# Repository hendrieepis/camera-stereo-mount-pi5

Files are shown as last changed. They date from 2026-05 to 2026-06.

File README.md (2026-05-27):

# Camera Stereo Mount Pi5 — 90°

Dudukan kamera CSI stereo untuk Raspberry Pi 5, konfigurasi siku 90°.
Repo ini berisi empat versi desain (V3, V4, V5, V6) dalam format OpenSCAD `.scad`.

---

## Kamera yang Didukung

Waveshare IMX219-83 Stereo Camera

Desain mount ini dibuat dan diuji untuk kamera:

**Waveshare Binocular Camera Module — IMX219-83 Stereo Camera**
- Sensor: Dual IMX219, 8 Megapixel per lensa
- FOV: 83°
- Antarmuka: CSI (kompatibel Raspberry Pi 5 dan Jetson Nano)
- Fitur: Stereo vision, depth vision
- Jarak antar lubang baut: 20.45mm (X) × 13.87mm (Y)
- Baut mounting: M2

Beli di: [Waveshare IMX219-83 Stereo Camera](https://www.waveshare.com/product/raspberry-pi/boards-kits/raspberry-pi-5/imx219-83-stereo-camera.htm)

---

## Perbedaan V3, V4, V5, V6

Keempat versi punya fungsi sama — menahan pelat kamera tegak lurus terhadap base
yang dibaut ke casing Raspberry Pi 5. Yang berbeda adalah **cara part disambung
dan apakah sudut kamera bisa disetel**.

| Aspek | V3 | V4 | V5 | V6 |
|---|---|---|---|---|
| Penyambung | Ball head (beli) | Batang ulir terpisah | Tidak ada — menyatu | Engsel knuckle BOSL2 |
| Jumlah part cetak | 2 | 3 | 1 | 2 |
| Ulir | 1/4"-20 (ke ball head) | 1/4"-20 (di rod) | Tidak ada | Tidak ada |
| Bisa dibongkar | Ya | Ya | Tidak | Ya |
| Setel sudut tilt | Ya (via ball head) | Tidak | Tidak | Ya, ±15° atas-bawah |
| Komponen beli | Ball head 1/4" | Threaded rod / baut M4 | — | Baut M4×25mm + mur M4 |

### V3 — dengan ball head
Part atas dan part bawah tidak tersambung langsung. Di antara keduanya
dipasang **ball head** (komponen tripod yang dibeli jadi). Part bawah punya
ulir male di puncak stick yang masuk ke lubang female ball head; part atas
punya lubang female yang menerima ulir male di atas ball head. Ball head
memberi kebebasan mengatur sudut kamera ke segala arah.

### V4 — batang ulir terpisah
Ball head dihilangkan. Sebagai gantinya dipakai **connector rod**: satu
batang dengan ulir male 1/4"-20 di kedua ujung dan batang polos di tengah.
Part atas dan part bawah dua-duanya punya lubang ulir female; connector rod
disekrup ke keduanya. Masih bisa dibongkar, tetapi sudut sudah tetap (90°).

Connector rod bisa dicetak, namun **disarankan memakai threaded rod 1/4"-20
dari logam** (potong sepanjang ±26 mm) karena ulir hasil cetak FDM rapuh
terhadap puntiran.

### V5 — satu objek utuh
Tanpa ulir, tanpa penyambung. Base, stick, dan pelat kamera **menyatu jadi
satu objek** yang dicetak sekaligus. Paling kuat dan paling sederhana, tetapi
tidak bisa dibongkar dan ukuran cetaknya paling besar.

### V6 — engsel tilt dengan friction lock
Pelat kamera bisa **tilt atas-bawah ±15°** dan dikunci di posisi manapun.
Menggunakan modul `knuckle_hinge()` dari library BOSL2. Ada dua part cetak:
bracket (base + stick + knuckle outer) dan tilt plate (pelat kamera + knuckle
inner). Poros engsel sekaligus pengunci menggunakan **baut M4 polos** (tidak
berulir di barrel) — baut tinggal ditusuk, mur dipasang di ujung, kencangkan
untuk mengunci sudut tilt.

---

## Cara Cetak — memisah part per versi

Pemisahan part dilakukan lewat variabel `mode` di dalam file `.scad`, dekat
bagian akhir file pada blok **MODE RENDER**.

Cara pakai: buka file di OpenSCAD → ubah nilai `mode` → tekan **F6** (render
penuh) → **File → Export → Export as STL** → ulangi untuk tiap part.

### Pilihan mode V3

```
mode = "all_parts";        // tampilan rakitan — JANGAN diexport STL
mode = "print_part_atas";  // pelat kamera + hub
mode = "print_part_bawah"; // base + stick
```

V3 menghasilkan **2 file STL**: part atas dan part bawah.
Ball head tidak dicetak — komponen beli.

### Pilihan mode V4

```
mode = "all_parts";           // tampilan rakitan — JANGAN diexport STL
mode = "print_part_atas";     // pelat kamera + hub berlubang ulir
mode = "print_part_bawah";    // base + stick + hub berlubang ulir
mode = "print_connector_rod"; // batang ulir penyambung (opsional)
```

V4 menghasilkan **3 file STL**: part atas, part bawah, connector rod.
Connector rod boleh dilewati bila memakai threaded rod logam.

### Pilihan mode V5

V5 hanya satu objek, tidak ada mode pemisahan part. Cukup buka file,
tekan F6, lalu export STL langsung.

### Pilihan mode V6

```
mode = "assembly";         // preview rakitan — JANGAN diexport STL
mode = "print_bracket";    // base + stick + knuckle outer engsel
mode = "print_tilt_plate"; // pelat kamera CSI + knuckle inner engsel
```

V6 menghasilkan **2 file STL**: bracket dan tilt plate.

Untuk preview sudut tilt di mode `assembly`, ubah variabel:

```
preview_tilt = 0;    // posisi tengah (default)
preview_tilt = 15;   // tilt ke belakang
preview_tilt = -15;  // tilt ke depan
```

### Catatan orientasi cetak

- V3 `print_part_atas` — sudah otomatis direbahkan, pelat tidur di bed.
- V3/V4 `print_part_bawah` — berdiri dengan base menempel di bed.
- V6 `print_bracket` — berdiri dengan base di bed, knuckle di atas.
- V6 `print_tilt_plate` — pelat tidur di bed, knuckle berdiri di sisi.
- Mode `all_parts` / `assembly` hanya untuk cek susunan, jangan diexport STL.

---

## Komponen Beli per Versi

### V3
- Ball head kamera 1/4"-20 (beli jadi, ukuran standar tripod)

### V4
- Threaded rod 1/4"-20 panjang ±26mm (bisa potong dari rod lebih panjang)
- Atau: baut 1/4"-20 + mur sebagai pengganti rod

### V5
- Tidak ada komponen beli

### V6
- **Baut M4 × 25mm, kepala socket (hex dalam / Allen)** — 1 buah
- **Mur M4** — 1 buah
- **Washer M4** — 2 buah (opsional, bikin tekanan pengunci lebih merata)

Cara pasang V6: tusuk baut dari satu sisi barrel knuckle (lubang polos,
tidak berulir, baut M4 langsung masuk bebas), pasang mur di sisi lain,
kencangkan dengan obeng hex + kunci 7mm hingga tilt plate terjepit dan
tidak bergerak. Kendorkan untuk ganti sudut tilt.

---

## Instalasi Library BOSL2

Semua versi (V3–V6) memakai library **BOSL2**. V3/V4 memakai `threading.scad`
untuk ulir; V5/V6 memakai `std.scad` dan `hinges.scad`. Tanpa BOSL2, file
tidak bisa dirender dan akan muncul error `Can't open include file`.

Library harus diletakkan di folder **libraries** milik OpenSCAD.

### Lokasi folder libraries

| OS | Lokasi |
|---|---|
| Windows | `Documents\OpenSCAD\libraries` |
| Linux | `~/.local/share/OpenSCAD/libraries` |

Cara pasti menemukannya: di OpenSCAD buka menu **File → Show Library Folder**.

### Cara 1 — Download manual (paling mudah)

1. Buka `https://github.com/BelfrySCAD/BOSL2/releases`
2. Download `Source code (zip)`
3. Ekstrak, ganti nama folder hasil ekstrak menjadi tepat `BOSL2`
4. Pindahkan folder `BOSL2` ke folder libraries

Struktur akhir yang benar:

```
libraries/
└── BOSL2/
    ├── std.scad
    ├── hinges.scad
    ├── threading.scad
    └── ... (file lain)
```

### Cara 2 — Lewat Git

#### Windows

```
mkdir %USERPROFILE%\Documents\OpenSCAD\libraries
cd %USERPROFILE%\Documents\OpenSCAD\libraries
git clone https://github.com/BelfrySCAD/BOSL2.git
```

#### Linux

```
mkdir -p ~/.local/share/OpenSCAD/libraries
cd ~/.local/share/OpenSCAD/libraries
git clone https://github.com/BelfrySCAD/BOSL2.git
```

### Verifikasi

Tutup dan buka ulang OpenSCAD, lalu buka salah satu file dan tekan F5.
Bila tidak ada error `Can't open include file 'BOSL2/std.scad'`, instalasi
berhasil.

---

## Ringkasan Parameter Penting

Parameter berada di bagian atas tiap file `.scad` dan bisa diubah langsung.
Setelah mengubah parameter, render ulang (F6) sebelum export STL.

---

## Lisensi

Desain ini dirilis di bawah lisensi **Creative Commons Attribution 4.0 International (CC BY 4.0)**.

Kamu bebas untuk:
- **Berbagi** — menyalin dan mendistribusikan materi ini dalam medium atau format apapun
- **Adaptasi** — menggubah, mengubah, dan membuat turunan dari materi ini untuk keperluan apapun, termasuk komersial

Dengan syarat:
- **Atribusi** — kamu harus mencantumkan kredit yang sesuai, menyertakan link ke lisensi, dan menyatakan jika ada perubahan yang dibuat. Kredit harus menyebut nama pembuat asli.

**Pembuat:** Akhmad Hendriawan — Wireless Sensor Network Laboratory, PENS (Politeknik Elektronika Negeri Surabaya)

**Repository:** https://github.com/hendrieepis/camera-stereo-mount-pi5

**Link lisensi:** https://creativecommons.org/licenses/by/4.0/

---

*Desain ini dibuat secara sukarela untuk melengkapi produk Waveshare IMX219-83
yang tidak disertai bracket/mount. Jika desain ini bermanfaat bagimu, cukup
cantumkan kredit dan bagikan ke orang lain yang membutuhkan.*

| Parameter | Versi | Fungsi |
|---|---|---|
| `cam_hole_dist_x` / `_y` | Semua | Jarak antar lubang baut kamera CSI |
| `m2_dia` | Semua | Diameter lubang baut kamera M2 (clearance) |
| `bottom_hole_margin` | Semua | Jarak lubang bawah ke tepi bawah pelat |
| `top_hole_margin` | Semua | Jarak lubang atas ke tepi atas pelat |
| `base_hole_dia` | Semua | Diameter 6 lubang M2 di base ke casing Raspi |
| `stick_height` | Semua | Tinggi batang stick |
| `tripod_screw_dia_female` | V3/V4 | Diameter lubang ulir — perbesar bila seret |
| `hinge_len` | V6 | Panjang barrel engsel (sumbu X) |
| `hinge_segs` | V6 | Jumlah segmen knuckle (ganjil = simetris) |
| `hinge_offset` | V6 | Jarak barrel dari permukaan leaf |
| `knuckle_d` | V6 | Diameter barrel engsel |
| `preview_tilt` | V6 | Sudut tilt untuk preview assembly (-15..+15) |

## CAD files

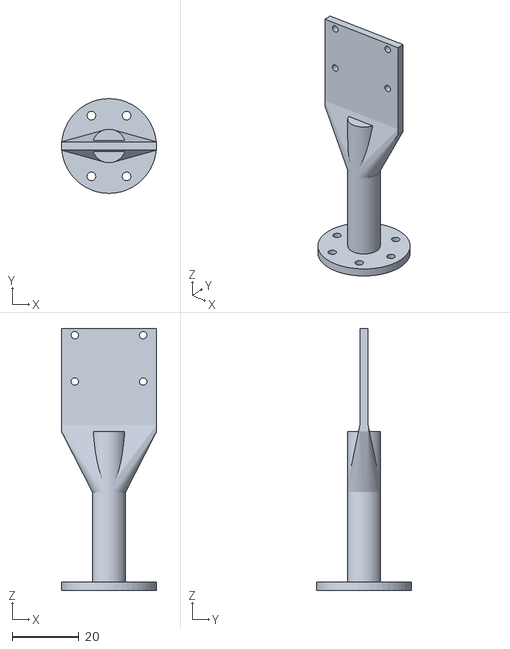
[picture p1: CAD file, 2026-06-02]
camera_stereo_mount_pi5-90deg-V5.stl
28.4 x 28.4 x 78.4

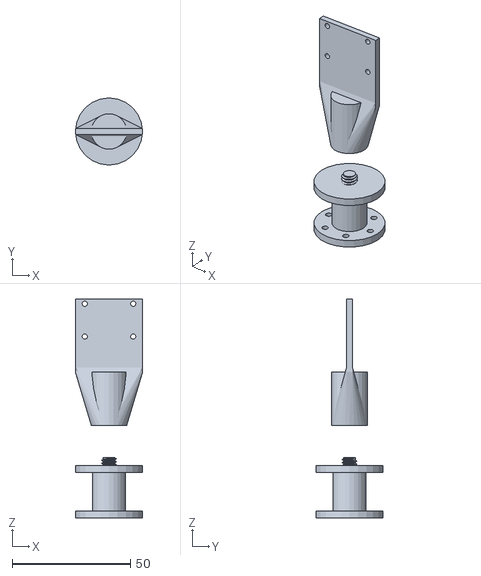
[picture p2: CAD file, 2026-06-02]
camera stereo mount pi5-90deg-V3.stl
28.4 x 28.4 x 92.5

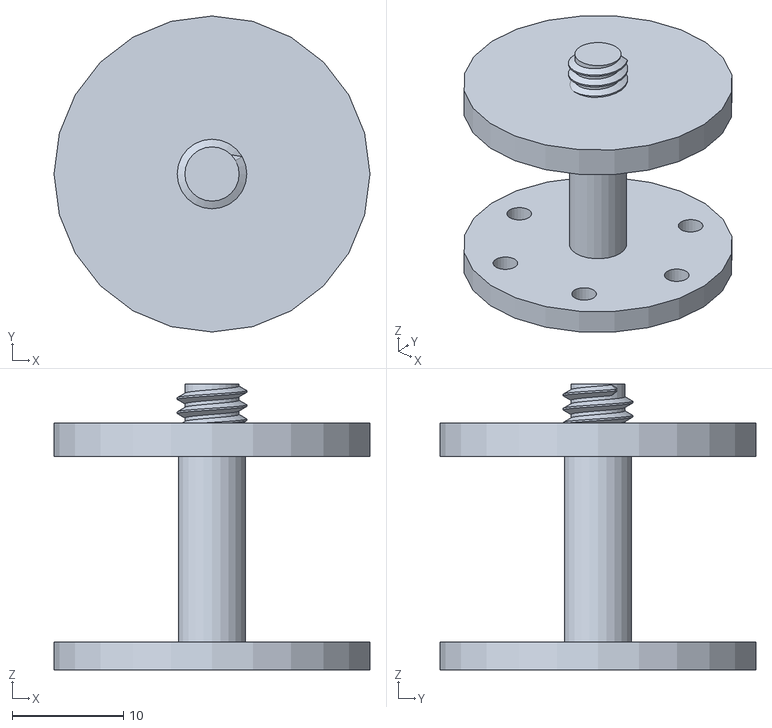
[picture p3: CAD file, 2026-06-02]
camera stereo mount pi5-90deg-V3-bawah.stl
28.4 x 28.4 x 25.6

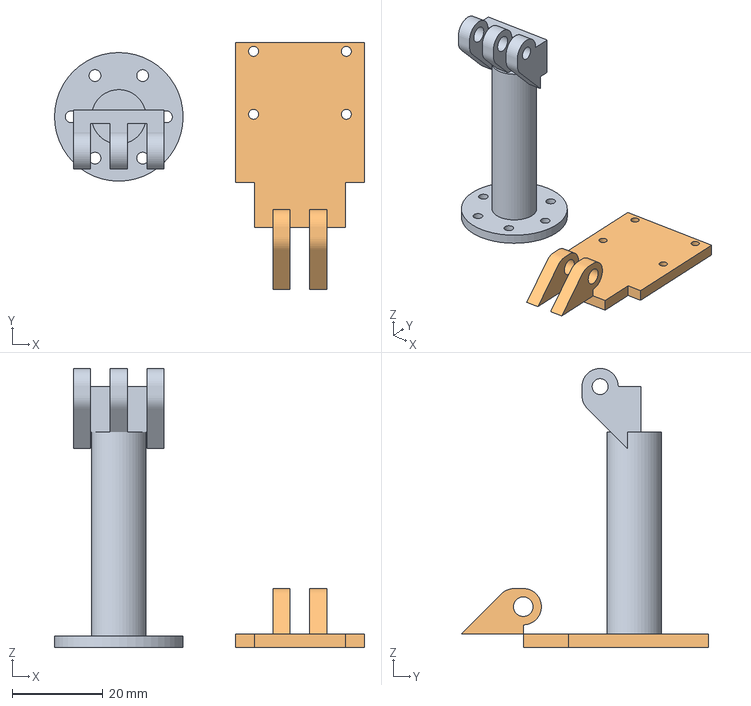
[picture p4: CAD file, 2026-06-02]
camera stereo-v6.3mf
68.3 x 54.5 x 61.5 mm
camera_stereo_mount_pi5-90deg-V6-bracket.stl
camera_stereo_mount_pi5-90deg-V6-plate.stl

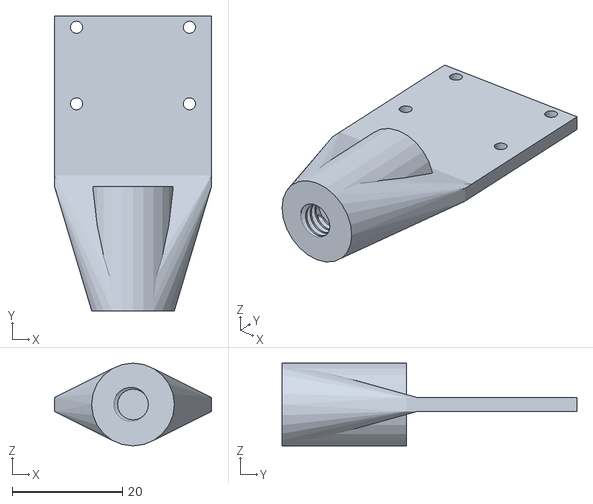
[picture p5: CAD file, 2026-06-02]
camera stereo mount pi5-90deg-V3-atas.stl
28.4 x 53.4 x 15.0

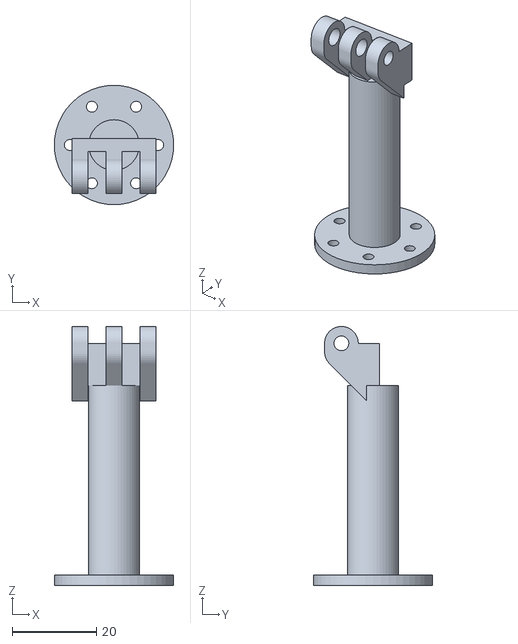
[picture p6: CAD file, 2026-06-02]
camera_stereo_mount_pi5-90deg-V6-bracket.stl
28.4 x 28.4 x 61.5

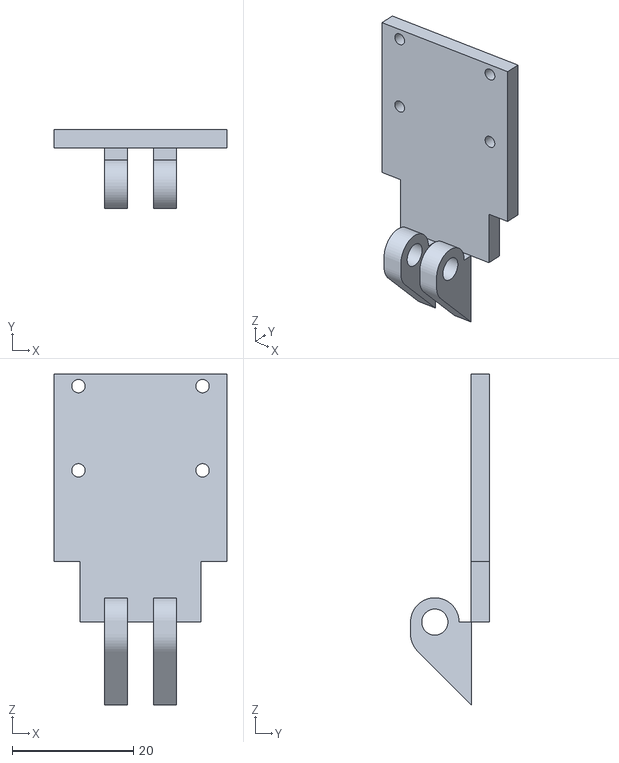
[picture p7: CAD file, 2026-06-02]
camera_stereo_mount_pi5-90deg-V6-plate.stl
28.4 x 13.0 x 54.5

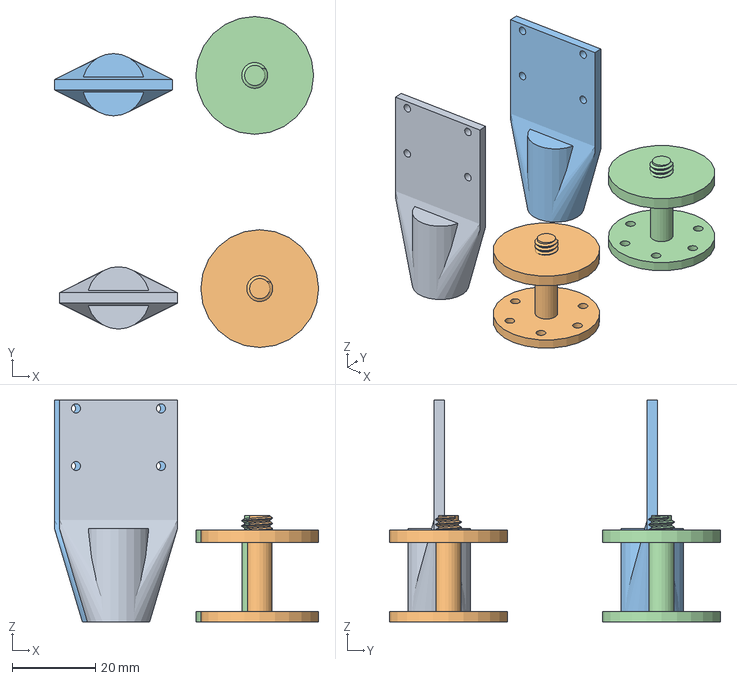
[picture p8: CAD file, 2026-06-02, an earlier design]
camera stereo-v4.3mf
63.6 x 79.6 x 53.4 mm
camera stereo mount pi5-90deg-V3-atas.stl x 2
camera stereo mount pi5-90deg-V3-bawah.stl x 2

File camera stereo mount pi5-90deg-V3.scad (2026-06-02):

// ==========================================
// BOSL2 LIBRARY
// ==========================================
include <BOSL2/std.scad>
include <BOSL2/threading.scad>

// ==========================================
// RESOLUTION CONTROL
// ==========================================
$fn = 24;

// ==========================================
// PARAMETER DEFINITION
// ==========================================

// Kamera
cam_hole_dist_x = 20.45;
cam_hole_dist_y = 13.87;

cam_plate_thick = 2.5;

m2_dia = 2.2;

// Jarak pusat lubang bawah dari tepi bawah pelat
bottom_hole_margin = 15;

// Jarak pusat lubang atas dari tepi atas pelat
top_hole_margin = 2;


// Ball Head
ball_head_dia = 28.35;
ball_head_height = 47.88;

// Thread tolerance FDM
tripod_screw_dia_male = 6.25;

// Female dilonggarkan: cukup untuk male printed
// (part bawah) maupun male logam (ball head).
// Naikkan angka ini kalau masih seret,
// turunkan kalau terlalu longgar/oblak.
tripod_screw_dia_female = 6.90;

screw_length = 7.0;


// Base
total_target_height = 70.0;

base_thick = 3;
top_sub_base_thick = 3.0;

stick_height =
    total_target_height
    - ball_head_height
    - base_thick
    - top_sub_base_thick;

stick_dia = 14.0;


// Lubang base bawah
num_base_holes = 6;
base_hole_radius = 10.5;

// Diameter lubang clearance baut M2 di base (6 buah).
// Bukan lubang ulir - baut hanya lewat, dikencangkan
// dengan mur di sisi casing Raspi 5.
base_hole_dia = 2.6;


// ==========================================
// BOSL2 THREAD MODULES
// ==========================================

// Male 1/4"-20 UNC
module tripod_male_thread(h=7)
{
    threaded_rod(
        d = tripod_screw_dia_male,
        l = h,
        pitch = 1.27,
        internal = false,
        blunt_start = true
    );
}


// Female 1/4"-20 UNC
module tripod_female_thread_cutter(h=8)
{
    threaded_rod(
        d = tripod_screw_dia_female,
        l = h,
        pitch = 1.27,
        internal = true,
        blunt_start = true
    );
}


// ==========================================
// PART ATAS
// ==========================================

module part_atas_camera_holder()
{
    plate_w = cam_hole_dist_x + 8;

    // tinggi pelat dihitung otomatis
    plate_h =
        bottom_hole_margin
        + cam_hole_dist_y
        + top_hole_margin;

    hub_height = 15;
    hub_dia = 15;

    // Offset vertikal pangkal pelat kamera.
    // hub_height/2 = pelat nempel di permukaan atas hub.
    plate_offset_z = hub_height/2;


    difference()
    {
        // ==================================
        // BODY UTAMA
        // ==================================
        union()
        {
            // Pelat kamera
            translate([
                -plate_w/2,
                -cam_plate_thick/2,
                plate_offset_z
            ])
                cube([
                    plate_w,
                    cam_plate_thick,
                    plate_h
                ]);


            // Sirip penguat
            hull()
            {
                translate([
                    -plate_w/2,
                    -cam_plate_thick/2,
                    plate_offset_z
                ])
                    cube([
                        plate_w,
                        cam_plate_thick,
                        2
                    ]);

                translate([0,0,-hub_height])
                    cylinder(
                        d = hub_dia,
                        h = 2
                    );
            }


            // Hub silinder
            translate([0,0,-hub_height])
                cylinder(
                    d = hub_dia,
                    h = hub_height + hub_height/2
                );
        }


        // ==================================
        // POSISI LUBANG KAMERA
        // ==================================

        // bawah pelat
        plate_bottom_z = plate_offset_z;

        // lubang bawah
        lower_hole_z =
            plate_bottom_z
            + bottom_hole_margin;

        // lubang atas
        upper_hole_z =
            lower_hole_z
            + cam_hole_dist_y;


        // kanan bawah
        translate([
            cam_hole_dist_x/2,
            -5,
            lower_hole_z
        ])
            rotate([-90,0,0])
                cylinder(
                    d = m2_dia,
                    h = 10
                );


        // kiri bawah
        translate([
            -cam_hole_dist_x/2,
            -5,
            lower_hole_z
        ])
            rotate([-90,0,0])
                cylinder(
                    d = m2_dia,
                    h = 10
                );


        // kanan atas
        translate([
            cam_hole_dist_x/2,
            -5,
            upper_hole_z
        ])
            rotate([-90,0,0])
                cylinder(
                    d = m2_dia,
                    h = 10
                );


        // kiri atas
        translate([
            -cam_hole_dist_x/2,
            -5,
            upper_hole_z
        ])
            rotate([-90,0,0])
                cylinder(
                    d = m2_dia,
                    h = 10
                );


        // ==================================
        // FEMALE THREAD
        // ==================================
        translate([0,0,-(hub_height+0.1)])
            tripod_female_thread_cutter(h=10);
    }
}



// ==========================================
// PART BAWAH
// ==========================================

module part_bawah_stick_and_base()
{
    difference()
    {
        union()
        {
            // Base bawah
            cylinder(
                d = ball_head_dia,
                h = base_thick
            );


            // Stick
            translate([0,0,base_thick])
                cylinder(
                    d = stick_dia,
                    h = stick_height
                );


            // Top base
            translate([
                0,
                0,
                base_thick + stick_height
            ])
                cylinder(
                    d = ball_head_dia,
                    h = top_sub_base_thick
                );


            // Male thread
            translate([
                0,
                0,
                base_thick
                + stick_height
                + top_sub_base_thick
            ])
                tripod_male_thread(h=screw_length);
        }


        // Lubang base bawah
        for (i = [0 : num_base_holes - 1])
        {
            angle = i * (360 / num_base_holes);

            rotate([0,0,angle])
                translate([
                    base_hole_radius,
                    0,
                    -1
                ])
                    cylinder(
                        d = base_hole_dia,
                        h = base_thick + 2
                    );
        }
    }
}



// ==========================================
// MODE RENDER
// ==========================================

mode = "all_parts";

// pilihan:
// "all_parts"
// "print_part_atas"
// "print_part_bawah"



if (mode == "all_parts")
{
    part_bawah_stick_and_base();

    translate([
        0,
        0,
        base_thick
        + stick_height
        + top_sub_base_thick
        + screw_length
        + 25
    ])
        part_atas_camera_holder();
}



if (mode == "print_part_atas")
{
    translate([0,0,cam_plate_thick/2])
        rotate([-90,0,0])
            part_atas_camera_holder();
}



if (mode == "print_part_bawah")
{
    part_bawah_stick_and_base();
}

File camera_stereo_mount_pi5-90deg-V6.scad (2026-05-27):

// ==========================================
// CAMERA STEREO MOUNT PI5 - 90 DEG - V6
// ------------------------------------------
// Dudukan kamera CSI stereo untuk Raspberry Pi 5.
// Engsel tilt atas-bawah +/-15 derajat.
// Pakai knuckle_hinge() BOSL2.
// Pengunci: baut M4 + mur (beli).
//
// 2 part cetak:
//   1. bracket   : base + stick + leaf + knuckle outer
//   2. tilt_plate: pelat kamera + leaf + knuckle inner
//
// Beli: baut M4 x 25mm + mur M4 (1 set)
// ==========================================

include <BOSL2/std.scad>
include <BOSL2/hinges.scad>

$fn = 48;

// ==========================================
// PARAMETER KAMERA CSI
// ==========================================
cam_hole_dist_x    = 20.45;
cam_hole_dist_y    = 13.87;
cam_plate_thick    = 3.0;
m2_dia             = 2.2;
bottom_hole_margin = 15;
top_hole_margin    = 2;

// ==========================================
// PARAMETER BASE & STICK
// ==========================================
base_thick     = 2.5;
base_disc_dia  = 28.35;
stick_height   = 45.0;
stick_dia      = 12.0;
num_base_holes = 6;
base_hole_r    = 10.5;
base_hole_dia  = 2.6;

// ==========================================
// PARAMETER ENGSEL
// ==========================================
hinge_len    = 20.0;   // panjang barrel (sejajar sumbu X)
hinge_segs   = 5;      // jumlah knuckle
hinge_offset = 6.0;    // offset barrel dari permukaan leaf
hinge_arm_h  = 2.0;    // tinggi arm
knuckle_d    = 8.0;    // diameter barrel
hinge_gap    = 0.25;   // gap antar segmen

// ==========================================
// DIMENSI TURUNAN
// ==========================================
plate_w     = cam_hole_dist_x + 8;
plate_h     = bottom_hole_margin + cam_hole_dist_y + top_hole_margin;
stick_top_z = base_thick + stick_height;

// Tebal leaf = tebal pelat kamera
leaf_thick  = cam_plate_thick;
// Tinggi leaf bracket (blok di puncak stick)
leaf_h      = 10.0;


// ==========================================
// BRACKET
// ------------------------------------------
// Leaf bracket berdiri di puncak stick.
// Knuckle outer tumbuh ke arah FRONT (+Y)
// dengan barrel sejajar sumbu X.
// Putaran engsel = tilt atas-bawah. ✓
// ==========================================

module bracket()
{
    difference()
    {
        union()
        {
            // Base
            cylinder(d = base_disc_dia, h = base_thick);

            // Stick
            translate([0, 0, base_thick])
                cylinder(d = stick_dia, h = stick_height);

            // Leaf bracket + knuckle outer
            translate([0, 0, stick_top_z + leaf_h/2])
                cuboid([hinge_len, leaf_thick, leaf_h])
                    position(TOP+FRONT) orient(anchor=FWD)
                        knuckle_hinge(
                            length       = hinge_len,
                            segs         = hinge_segs,
                            offset       = hinge_offset,
                            inner        = false,
                            arm_height   = hinge_arm_h,
                            pin_diam     = "M4",
                            knuckle_diam = knuckle_d,
                            gap          = hinge_gap,
                            fill         = true
                        );
        }

        // 6 lubang base clearance M2
        for (i = [0 : num_base_holes - 1])
            rotate([0, 0, i * 360/num_base_holes])
                translate([base_hole_r, 0, -1])
                    cylinder(d = base_hole_dia, h = base_thick + 2);
    }
}


// ==========================================
// TILT PLATE (koordinat lokal, z mulai 0)
// ------------------------------------------
// Leaf tilt di bawah pelat.
// Knuckle inner tumbuh ke arah FRONT (+Y)
// dengan barrel sejajar sumbu X. ✓
// ==========================================

module tilt_plate_local()
{
    difference()
    {
        union()
        {
            // Leaf + knuckle inner
            // Leaf dari z=0 ke z=leaf_h
            translate([0, 0, leaf_h/2])
                cuboid([hinge_len, leaf_thick, leaf_h])
                    position(BOT+FRONT) orient(anchor=FWD)
                        knuckle_hinge(
                            length       = hinge_len,
                            segs         = hinge_segs,
                            offset       = hinge_offset,
                            inner        = true,
                            arm_height   = hinge_arm_h,
                            pin_diam     = "M4",
                            knuckle_diam = knuckle_d,
                            gap          = hinge_gap,
                            fill         = true
                        );

            // Pelat kamera di atas leaf
            translate([
                -plate_w/2,
                -leaf_thick/2,
                leaf_h
            ])
                cube([plate_w, leaf_thick, plate_h]);
        }

        // 4 lubang kamera CSI (M2 clearance)
        lower_z = leaf_h + bottom_hole_margin;
        upper_z = lower_z + cam_hole_dist_y;

        for (sx = [-1, 1])
            for (hz = [lower_z, upper_z])
                translate([sx * cam_hole_dist_x/2, -5, hz])
                    rotate([-90, 0, 0])
                        cylinder(d = m2_dia, h = 10);
    }
}


// ==========================================
// TILT PLATE dalam koordinat dunia
// Pusat rotasi = sumbu barrel knuckle
// ==========================================

module tilt_plate_world(tilt_angle = 0)
{
    // Barrel knuckle bracket ada di:
    //   z = stick_top_z + leaf_h (TOP leaf) + arm + knuckle_d/2
    //     = poros engsel dalam dunia
    //   y = leaf_thick/2 + hinge_offset + hinge_arm_h + knuckle_d/2
    pivot_z = stick_top_z + leaf_h + hinge_arm_h + knuckle_d/2;
    pivot_y = leaf_thick/2 + hinge_offset + hinge_arm_h + knuckle_d/2;

    // tilt_plate_local: barrel-nya ada di
    //   z lokal = 0 (BOT leaf), tapi BOT leaf posisi di z=0
    //   karena inner, knuckle tumbuh ke bawah dari BOT leaf
    //   barrel center = z_lokal=0 - arm - knuckle_d/2 = -(arm+kd/2)
    //
    // Supaya barrel lokal bertemu barrel bracket:
    //   z_world(barrel lokal) = pivot_z
    //   translate_z + lokal_barrel_z = pivot_z
    //   translate_z + 0 - (arm+kd/2) = pivot_z - (arm+kd/2) ... hmm
    //
    // Cara paling aman: translate leaf BOT ke pivot_z
    // karena inner tumbuh dari BOT leaf ke arah +y (FRONT)
    // dan bracket outer tumbuh dari TOP leaf ke arah +y (FRONT)
    // Mereka mesh saat leaf BOT inner = leaf TOP outer
    //   leaf TOP outer z = stick_top_z + leaf_h
    //   leaf BOT inner z = pivot_z (yang kita terjemahkan)

    plate_translate_z = stick_top_z + leaf_h;

    // Rotasi pada sumbu X di posisi poros
    translate([0, pivot_y, pivot_z])
        rotate([tilt_angle, 0, 0])
            translate([0, -pivot_y, -pivot_z])
                translate([0, 0, plate_translate_z])
                    tilt_plate_local();
}


// ==========================================
// MODE RENDER
// ==========================================

mode = "assembly";

// pilihan:
// "assembly"         - preview rakitan
// "print_bracket"    - cetak bracket
// "print_tilt_plate" - cetak tilt plate

preview_tilt = 0;   // sudut preview (-15..+15)


if (mode == "assembly")
{
    color("gold") bracket();
    color("cyan") tilt_plate_world(preview_tilt);
}

if (mode == "print_bracket")
    bracket();

if (mode == "print_tilt_plate")
    tilt_plate_local();

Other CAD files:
camera stereo-v5.3mf
camera_stereo_mount_pi5-90deg-V4.scad
camera_stereo_mount_pi5-90deg-V5.scad
